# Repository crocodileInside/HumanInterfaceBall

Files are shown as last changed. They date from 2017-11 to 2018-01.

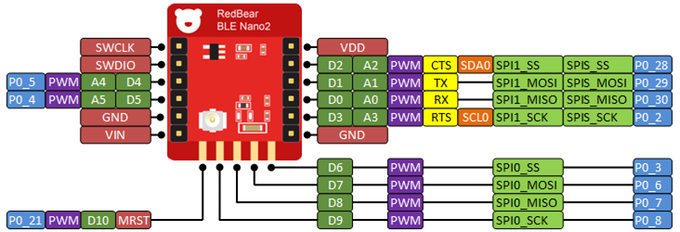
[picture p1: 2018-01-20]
Datasheets/BLE_Nano_v2_Pinout.png

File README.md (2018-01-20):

# HumanInterfaceBall
A ball-shaped, BLE enabled human interface device using a **Bosch BNO055** IMU and a **Bosch BME280** environment sensor for mouse input control.  

## Hardware  
Using a RedBearLabs BLE Nano v2 (**nRF52832**) as MCU and for BLE communication.

## Software  
Written in Arduino, see Arduino folder

### Installation instructions  
In order to setup the required toolchain, follow these instructions:

1. Download and install [Arduino IDE](https://www.arduino.cc/en/Main/Software) >=1.6.12 (tested with 1.6.12)  
2. Install `arduino-nRF5` as described here: https://github.com/sandeepmistry/arduino-nRF5
3. Copy the contents of the `Arduino/libraries/` folder to your Arduino library folder (most likely at `Documents/Arduino/libraries`)
4. The default pin function mapping of our board in Arduino doesn't work with our PCB, so you need to replace your `variant.h` with the one provided in `Arduino/variant.h`  
The original variant.h is found at `C:\Users\<Username>\AppData\Local\Arduino15\packages\sandeepmistry\hardware\nRF5\0.4.0\variants\RedBear_BLENano2`
5. Plug in the DAPLink
6. Install the [mbed Serial Driver](https://os.mbed.com/handbook/Windows-serial-configuration)
7. Open the Arduino IDE (or restart, if it was open)
8. Choose *Tools -> Board -> RedBear BLE Nano 2*
9. Choose *Tools -> Softdevice -> S132*
10. Select the correct serial port for the DAPLink at *Tools -> Port* (sometimes displayed as *BBC:microBit*)
11. Choose *Tools -> Programmer -> CMSIS-DAP*
12. **factory new boards only**: Select *Tools -> nRF5 Flash SoftDevice* and wait for completion
13. Compile and flash the software using Arduino (or hit CTRL+U)
14. Finished!

*Created 01/2018 by C. Locher, M. Schuster, S. Oechslein, N. Rieth, T. Windberg*

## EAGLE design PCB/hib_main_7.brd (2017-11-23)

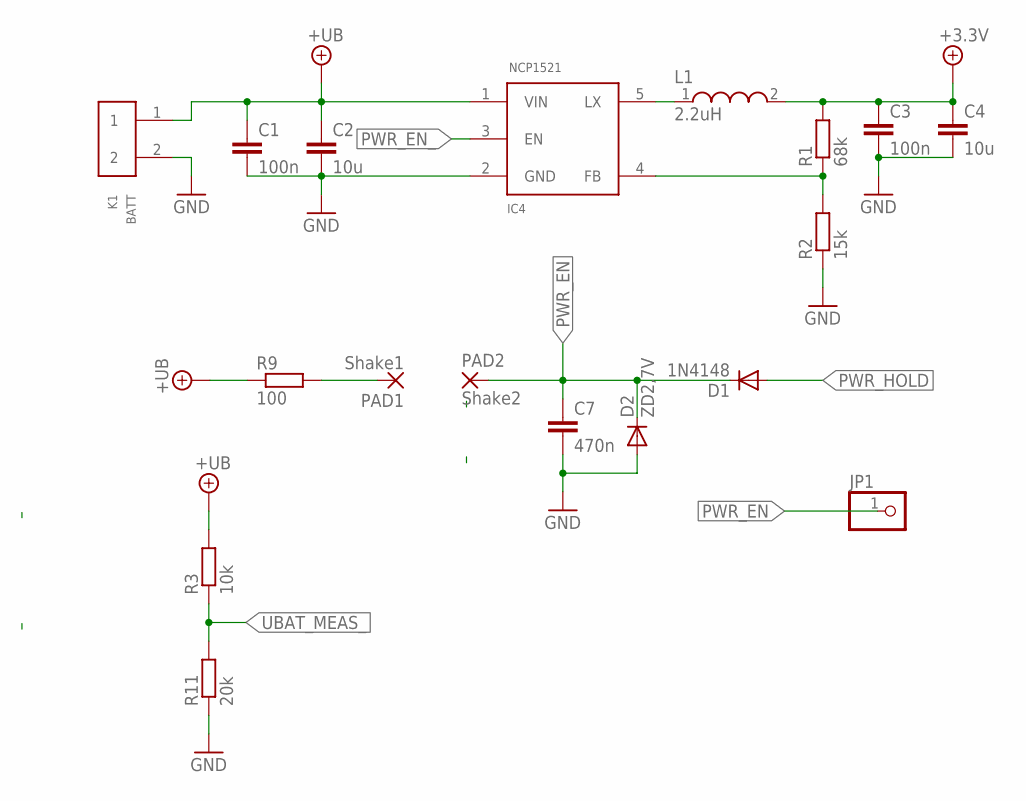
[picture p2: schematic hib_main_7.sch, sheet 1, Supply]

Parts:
C1: 100n; C0805K
C2: 10u; C0805K
C3: 100n; C0805M
C4: 10u; C0805M
C7: 470n; C0805M
D1: 1N4148; MINIMELF
D2: ZD2,7V; MINIMELF
IC4: NCP1521; SOT23-5L
JP1: PINHD-1X1; 1X01
K1: BATT; 620102131822
L1: 2.2uH; WE-MPSB_0805(W=4.0)
PAD1: Shake1; SMD1,27-2,54
PAD2: Shake2; SMD1,27-2,54
R1: 68k; R0603
R2: 15k; R0603
R3: 10k; R0603
R9: 100; R0603
R11: 20k; R0603

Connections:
+3,3V: C3.1, C4.1, L1.2, R1.2; also elsewhere on the board
+UB: C1.1, C2.1, IC4.1 (VIN), K1.1, R3.2, R9.1; also elsewhere on the board
GND: C1.2, C2.2, C3.2, C4.2, C7.2, D2.A, IC4.2 (GND), K1.2, R2.1, R11.1; also elsewhere on the board
unnamed: IC4.5 (LX), L1.1
unnamed: IC4.4 (FB), R1.1, R2.2
unnamed: PAD1.1, R9.2
PWR_EN: C7.1, D1.C, D2.C, JP1.1, PAD2.1
PWR_EN_: IC4.3 (EN); also elsewhere on the board
PWR_HOLD: D1.A; also elsewhere on the board
UBAT_MEAS_: R3.1, R11.2; also elsewhere on the board

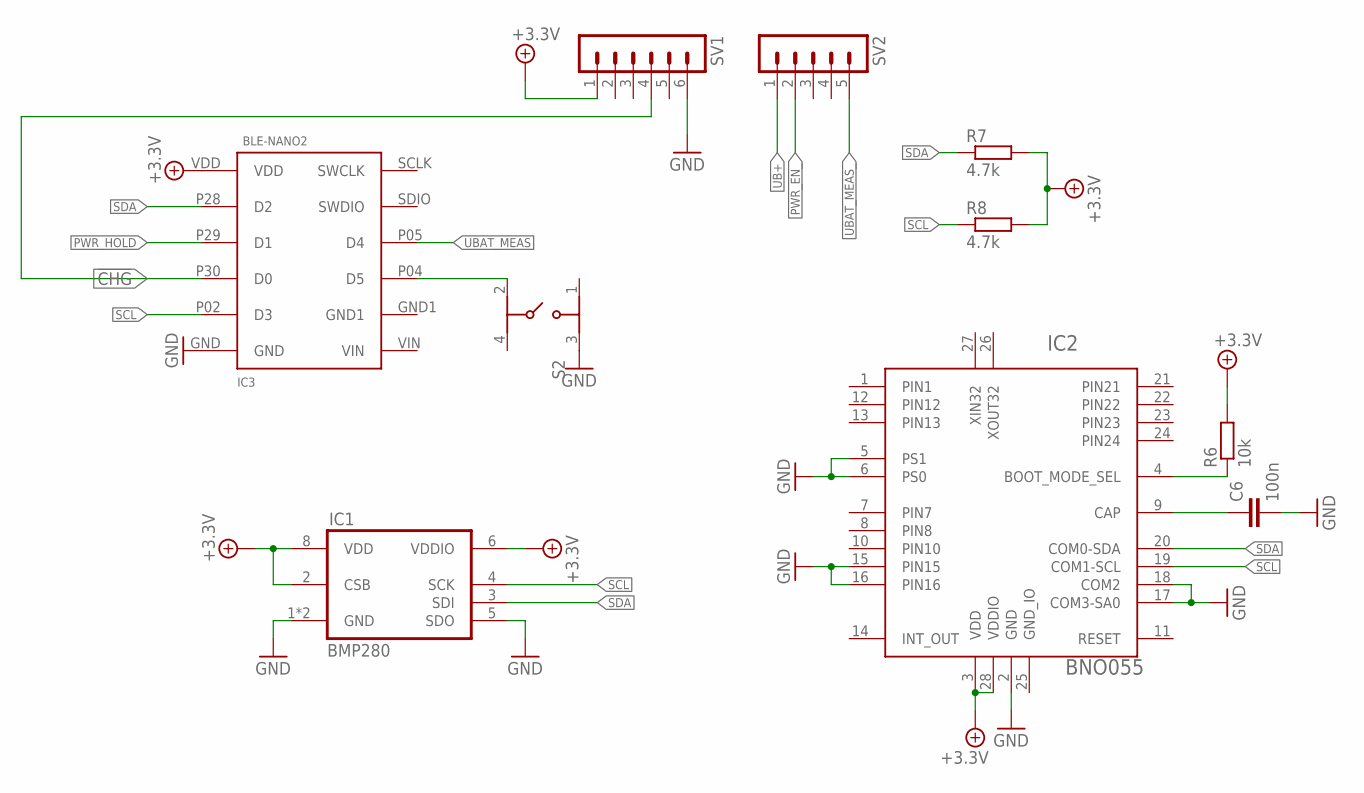
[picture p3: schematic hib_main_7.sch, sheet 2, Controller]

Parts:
C6: 100n; C0805M
IC1: BMP280
IC2: BNO055; LGA-28_3.80X5.20/0.5
IC3: BLE-NANO2
R6: 10k; R0805M
R7, R8: 4.7k; R0805M
S2: 434153017835
SV1: MA06-1
SV2: MA05-1

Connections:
!CHG!: IC3.P30 (D0), SV1.4; also elsewhere on the board
+3,3V: IC1.2 (CSB), IC1.6 (VDDIO), IC1.8 (VDD), IC2.3 (VDD), IC2.28 (VDDIO), IC3.VDD, R6.2, R7.2, R8.2, SV1.1; also elsewhere on the board
GND: C6.2, IC1.1 (GND), IC1.5 (SDO), IC1.7 (GND), IC2.2 (GND), IC2.5 (PS1), IC2.6 (PS0), IC2.15 (PIN15), IC2.16 (PIN16), IC2.17 (COM3-SA0), IC2.18 (COM2), IC3.GND, S2.3 (2), SV1.6; also elsewhere on the board
GND_IO: IC2.25 (GND_IO)
unnamed: C6.1, IC2.9 (CAP)
unnamed: IC2.4 (BOOT_MODE_SEL), R6.1
PWR_EN_: SV2.2; also elsewhere on the board
PWR_HOLD: IC3.P29 (D1); also elsewhere on the board
RESET: IC3.P04 (D5), S2.2 (3)
SCL: IC1.4 (SCK), IC2.19 (COM1-SCL), IC3.P02 (D3), R8.1
SDA: IC1.3 (SDI), IC2.20 (COM0-SDA), IC3.P28 (D2), R7.1
UB+: SV2.1
UBAT_MEAS: IC3.P05 (D4)
UBAT_MEAS_: SV2.5; also elsewhere on the board

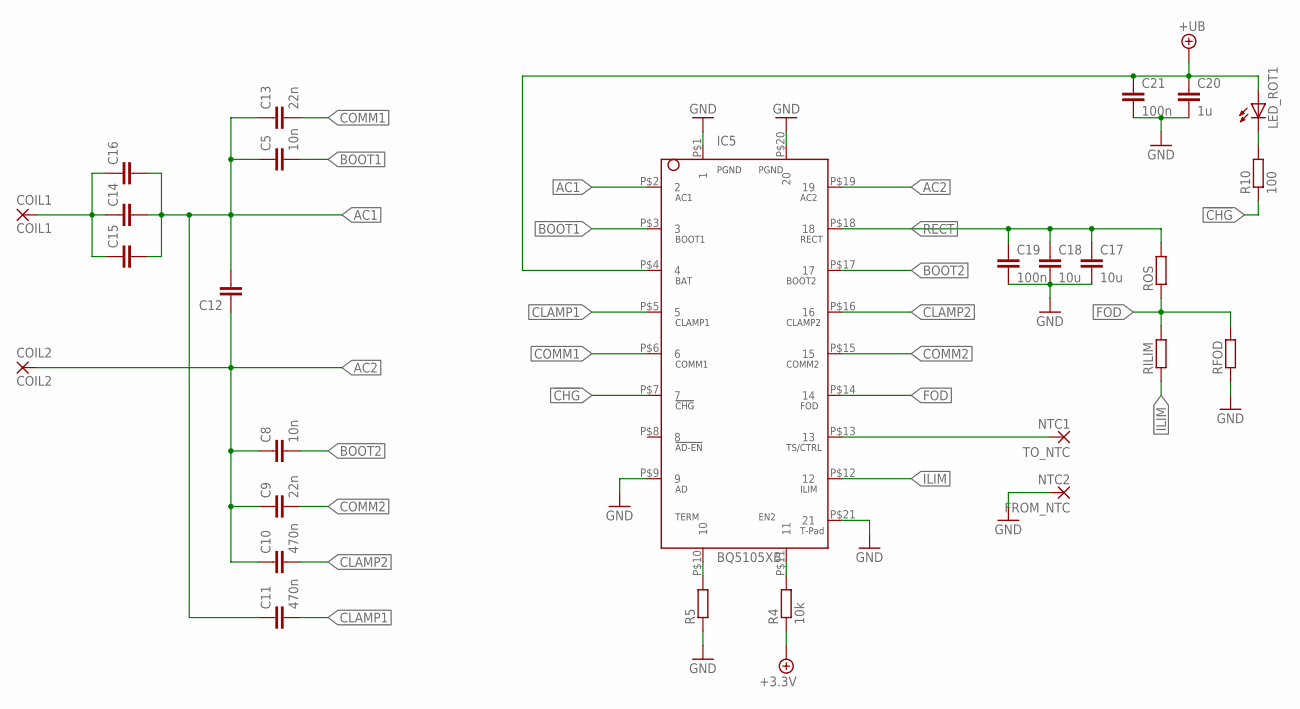
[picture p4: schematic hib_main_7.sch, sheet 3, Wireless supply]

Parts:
C5, C8: 10n; C0603K
C9, C13: 22n; C0603K
C10, C11: 470n; C0603K
C12, C14, C15, C16: C-EUC0603K; C0603K
C17, C18: 10u; C0603K
C19, C21: 100n; C0603K
C20: 1u; C0603K
COIL1: COIL1; SMD1,27-2,54
COIL2: COIL2; SMD1,27-2,54
FROM_NTC: NTC2; SMD1,27-2,54
IC5: BQ5105XB; VQFN_BQ5105B
LED_ROT1: LEDCHIP-LED0603; CHIP-LED0603
R4: 10k; R0805
R5: R-EU_R0603; R0603
R10: 100; R0603
RFOD: R-EU_R0805; R0805
RILIM: R-EU_R0805; R0805
ROS: R-EU_R0805; R0805
TO_NTC: NTC1; SMD1,27-2,54

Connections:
!CHG!: IC5.P$7 (7), R10.1; also elsewhere on the board
+3,3V: R4.1; also elsewhere on the board
+UB: C20.1, C21.1, IC5.P$4 (4), LED_ROT1.A; also elsewhere on the board
AC1: C5.1, C11.1, C12.2, C13.1, C14.2, C15.2, C16.2, IC5.P$2 (2)
AC2: C8.1, C9.1, C10.1, C12.1, COIL2.1, IC5.P$19 (19)
BOOT1: C5.2, IC5.P$3 (3)
BOOT2: C8.2, IC5.P$17 (17)
CLAMP1: C11.2, IC5.P$5 (5)
CLAMP2: C10.2, IC5.P$16 (16)
COMM1: C13.2, IC5.P$6 (6)
COMM2: C9.2, IC5.P$15 (15)
FOD: IC5.P$14 (14), RFOD.2, RILIM.2, ROS.1
GND: C17.2, C18.2, C19.2, C20.2, C21.2, FROM_NTC.1, IC5.P$1 (1), IC5.P$9 (9), IC5.P$20 (20), IC5.P$21 (21), R5.1, RFOD.1; also elsewhere on the board
ILIM: IC5.P$12 (12), RILIM.1
unnamed: C14.1, C15.1, C16.1, COIL1.1
unnamed: IC5.P$10 (10), R5.2
unnamed: IC5.P$11 (11), R4.2
unnamed: LED_ROT1.C, R10.2
RECT: C17.1, C18.1, C19.1, IC5.P$18 (18), ROS.2
TS/CTRL: IC5.P$13 (13), TO_NTC.1

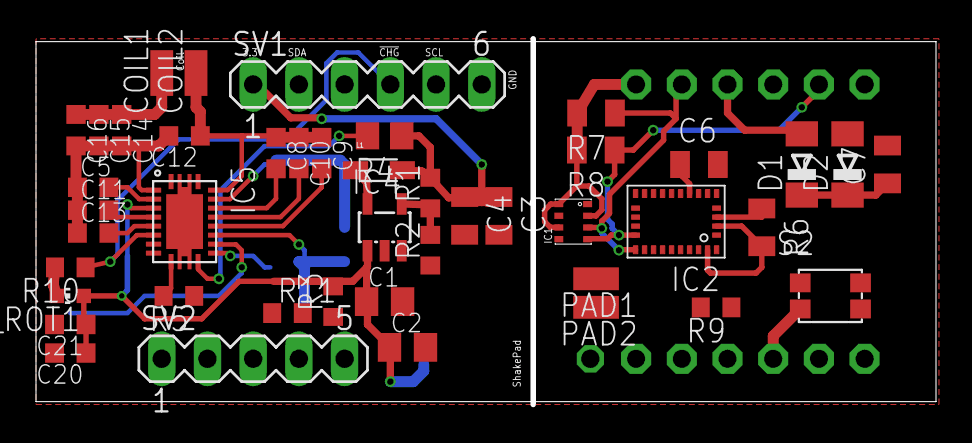
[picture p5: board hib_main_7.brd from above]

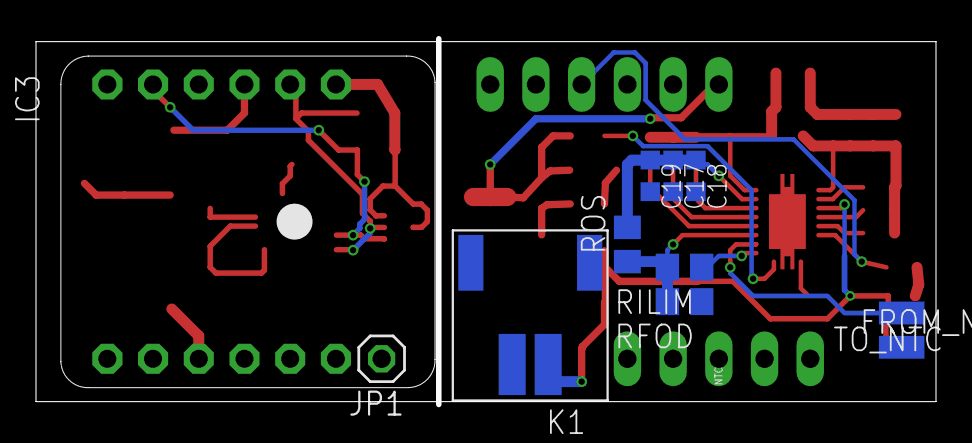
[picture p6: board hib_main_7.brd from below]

Board: 2 copper layers, 50.0 x 20.0 mm, 55 parts (11 on the bottom side), 32 nets.

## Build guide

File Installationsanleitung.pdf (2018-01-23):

# HumanInterfaceBall

Ein Soft-Ball mit einer Bosch BNO055 IMU und einem Bosch BME280 Umweltsensor zur Maussteuerung via Bluetooth 4.0LE.

# Hardware

Basiert auf dem RedBearLabs BLE Nano v2 (nRF52832) als Microcontroller und Bluetooth-Modul.

# Software

Entwickelt in Arduino. Anleitung zur Einrichtung der Entwicklungsumgebung, siehe unten.

## Installationsanleitung

Um mit Arduino den Controller programmieren zu können, muss mit folenden Schritten die Entwicklungsumgebung eingerichtet werden:

1. Herunterladen und installieren der Arduino IDE (https://www.arduino.cc/en/Main/Software) >=1.6.12 (getestet mit 1.6.12)
2. Die Erweiterung arduino-nRF5 nach Anleitung installieren: https://github.com/sandeepmistry/arduino-nRF5
3. Den Inhalt des Ordners Arduino/libraries/ in den eigenen Arduino-Library Ordner kopieren (normalerweise unter Dokumente/Arduino/libraries )

4. Die originale Pinbelegung der arduino-nRF5 Erweiterung passt nicht mit unseren Platinen zusammen, also muss die originale variant.h mit der aus Arduino/variant.h ersetzt werden. Die originale variant.h befindet sich normalerweise unter
C:\Users\
<Benutzername>\AppData\Local\Arduino15\packages\sandeepmistry\hardware\nRF5\0.4.0\variants\RedBear_BLENano2
5. Den Programmieradapter (DAPLink) mit dem Computer verbinden
6. Den mbed Serial Driver (https://os.mbed.com/handbook/Windows-serial-configuration) installieren
7. Die Arduino IDE öffnen (oder neu starten, wenn bereits geöffnet)
8. Werkzeuge -> Board -> RedBear BLE Nano 2 auswählen
9. Werkzeuge -> Softdevice -> S132 auswählen
10. Den korrekten Anschluss des Programmieradapters auswählen unter Werzeuge -> Port (wird manchmal als BBC:microBit angezeigt)
11. Werkzeuge -> Programmer -> CMSIS-DAP auswählen
12. wenn Fabrikneues Board: Werkzeuge -> nRF5 Flash SoftDevice auswählen, und auf Abschluss warten.
13. Software compilieren und hochladen (grüner Haken links oben, oder STRG-U)
14. Fertig!

Erstellt 01/2018 von C. Locher, M. Schuster, S. Oechslein, N. Rieth, T. Windberg

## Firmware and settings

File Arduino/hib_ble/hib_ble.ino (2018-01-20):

#include <SPI.h>
#include <BLEHIDPeripheral.h>
#include <BLEMouse.h>
#include <BLEKeyboard.h>
#include <BLEMultimedia.h>
#include <Wire.h>
#include <Adafruit_Sensor.h>
#include <Adafruit_BNO055.h>
#include <Adafruit_BME280.h>
#include <utility/imumaths.h>

#define MouseBtnLeft   0x01
#define MouseBtnRight  0x02
#define MouseBtnMiddle 0x04

//custom boards may override default pin definitions with BLEHIDPeripheral(PIN_REQ, PIN_RDY, PIN_RST)
BLEHIDPeripheral bleHIDPeripheral = BLEHIDPeripheral();
BLEMouse bleMouse;
BLEKeyboard bleKeyboard;



int buttonState;
int joystickXCenter;
int joystickYCenter;
int Hold_Var=0;
float basePressure = 954.0f;
float accX=0, accY=0,accZ=0;
int pos_acc=0;



Adafruit_BNO055 bno = Adafruit_BNO055();
Adafruit_BME280 bme;



void displaySensorStatus(void)
{
  /* Get the system status values (mostly for debugging purposes) */
  uint8_t system_status, self_test_results, system_error;
  system_status = self_test_results = system_error = 0;
  bno.getSystemStatus(&system_status, &self_test_results, &system_error);

  /* Display the results in the Serial Monitor */
  Serial.println("");
  Serial.print("System Status: 0x");
  Serial.println(system_status, HEX);
  Serial.print("Self Test:     0x");
  Serial.println(self_test_results, HEX);
  Serial.print("System Error:  0x");
  Serial.println(system_error, HEX);
  Serial.println("");
  delay(500);
}

#define LED 0



void doCalibration(){

  int numSamples = 50;
  float pAvg = 0.0f;

  for(int i=0; i<numSamples; i++){
    pAvg += bme.readPressure() / 100.0f;
    
    delay(10);
  }

  pAvg = pAvg / (float)numSamples;
  basePressure = pAvg;
}

void setup() {
  Serial.begin(115200);

  pinMode(LED, OUTPUT);
  digitalWrite(LED, 1);
  /*if (buttonState == LOW) {
    Serial.println(F("BLE HID Peripheral - clearing bond data"));

    // clear bond store 
    bleHIDPeripheral.clearBondStoreData();

  //}*/

  bleHIDPeripheral.clearBondStoreData();
  bleHIDPeripheral.setReportIdOffset(1);

  bleHIDPeripheral.setLocalName("HIB1");
  bleHIDPeripheral.addHID(bleMouse);
  bleHIDPeripheral.addHID(bleKeyboard);

  bleHIDPeripheral.begin();

  Serial.println(F("BLE Human Interface Ball"));

  joystickXCenter = 0;
  joystickYCenter = 0;

  Serial.println("starting BNO");
  if(!bno.begin()){
    Serial.println("no BNO055 detected!");
  }
  Serial.println("BNO setCrystal");
  bno.setExtCrystalUse(false);

  if(!bme.begin()){
    Serial.println("no BME280 detected!");
  }

  doCalibration();
  
  Serial.println("Setup complete");
  
}

int i = 0;
int ledstate = 0;


#define ROLL_AVG_SIZE   32
float gyroAvgArrX[ROLL_AVG_SIZE];
float gyroAvgArrY[ROLL_AVG_SIZE];
float gyroAvgArrZ[ROLL_AVG_SIZE];

float rollAvg(float arr[], float newValue){
  memmove(&(arr[1]), arr, (ROLL_AVG_SIZE-1)*sizeof(float));
  arr[0] = newValue;

  float avg = 0.0f;
  for(int i=0; i<ROLL_AVG_SIZE; i++){
    avg += arr[i];
  }

  return (avg / (float)ROLL_AVG_SIZE);
}


float oriX, oriY, oriZ;
float dOriX, dOriY, dOriZ;
float oriXold = 0.0f, oriYold = 0.0f, oriZold = 0.0f;

float gyroX = 0.0f, gyroY = 0.0f, gyroZ = 0.0f;
float gyroXold = 0.0f, gyroYold = 0.0f, gyroZold = 0.0f;
float dX = 0.0f, dY = 0.0f, dZ = 0.0f;

float sx = 0.0f, sy=0.0f, sz=0.0f;
float avgXold = 0.0f, avgYold = 0.0f, avgZold = 0.0f;


int moveLockTimeout = 0;

void loop() {
  Serial.println("BLE getCentral");
  BLECentral central = bleHIDPeripheral.central();

  //displaySensorStatus();

  uint8_t system, gyro, accel, mag = 0;
  bno.getCalibration(&system, &gyro, &accel, &mag);
  Serial.print("CALIBRATION: Sys=");
  Serial.print(system, DEC);
  Serial.print(" Gyro=");
  Serial.print(gyro, DEC);
  Serial.print(" Accel=");
  Serial.print(accel, DEC);
  Serial.print(" Mag=");
  Serial.println(mag, DEC);

  ledstate = !ledstate;
  digitalWrite(LED, ledstate);
  delay(200);
  
  
  if (central) {
    // central connected to peripheral
    Serial.print(F("Connected to central: "));
    Serial.println(central.address());
  










    while (central.connected()) {

      float pressure = bme.readPressure()/100.0f;
      float dP = pressure - basePressure;
      int tempButtonState = 0;



      //Middle Button Click for scroll function
      imu::Vector<3> acc = bno.getVector(Adafruit_BNO055::VECTOR_LINEARACCEL);

      accX= acc.x();
      accY= acc.y();
      accZ= acc.z();

      if((accY >=10.0f)||(accZ >=10.0f)){
        pos_acc=1;
      }
      if(pos_acc == 1 && (accY<=-10.0f||accZ<=-10.0f)){
        tempButtonState=4;
        }     
      
      //Serial.println(dP);
      if(dP>=20){
        tempButtonState=3;        
      }else if(dP > 1.0f && dP < 20.0f){
          tempButtonState = 1;      // Left Button click
          if(dP < 10.0f){
            Hold_Var=0;
            moveLockTimeout = 50;   // mouse freeze
          }else{
            Hold_Var = 1; 
          }
      }else if(dP < 1.0f && pos_acc != 1){
        tempButtonState = 2;
      }
      
      if ((tempButtonState != buttonState)) {
        buttonState = tempButtonState;
        switch(buttonState)
        {
          case 1: { // Press Mouse Btn Left
            //Serial.println(F("Mouse press"));   // Left press Button
            bleMouse.press(MouseBtnLeft);
            bleMouse.release(MouseBtnMiddle);
            pos_acc=0;
            break;
          }                  
          case 2: { // Release Mouse Btn Left
            //Serial.println(F("Mouse release")); // Left release Button
            if(Hold_Var != 1){
            bleMouse.release(MouseBtnLeft);
            }
            break;
          }
          case 3: { // Click Mouse Btn Right    // Right Button click
            moveLockTimeout = 50;
            bleMouse.click(MouseBtnRight);
            moveLockTimeout = 50;
            break;
          }
          case 4: { // Click Mouse Btn Right    // Middle Button press
            moveLockTimeout = 100;
            bleMouse.press(MouseBtnMiddle);
            moveLockTimeout = 100;
            break;
          }
          default: {break;}       
        }
      }

      imu::Vector<3> gyro = bno.getVector(Adafruit_BNO055::VECTOR_GYROSCOPE);
      gyroX = gyro.x();
      gyroY = gyro.y();
      gyroZ = gyro.z();
      sx += gyroX;
      sy += gyroY;
      sz += gyroZ;
      float avgX = rollAvg(gyroAvgArrX, sx);
      float avgY = rollAvg(gyroAvgArrY, sy);
      float avgZ = rollAvg(gyroAvgArrZ, sz);
      dX = avgX - avgXold;
      dY = avgY - avgYold;
      dZ = avgZ - avgZold;
      avgXold = avgX;
      avgYold = avgY;
      avgZold = avgZ;
      
      int x = dY/5.0f;
      int y = dX/5.0f;
      int z = dZ/5.0f;

      if(moveLockTimeout > 0){
        x = 0;
        y = 0;
        moveLockTimeout--;
      }

      if (x || y) {
        bleMouse.move(x, y, z);
        //Serial.print("Z:"); Serial.print(z);
      }

      ledstate = !ledstate;
      digitalWrite(LED, ledstate);
      
    }

    // central disconnected
    Serial.print(F("Disconnected from central: "));
    Serial.println(central.address());
    bleHIDPeripheral.clearBondStoreData();
  }
}

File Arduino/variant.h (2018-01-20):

/*
  Copyright (c) 2014-2015 Arduino LLC.  All right reserved.
  Copyright (c) 2016 Sandeep Mistry All right reserved.
  This library is free software; you can redistribute it and/or
  modify it under the terms of the GNU Lesser General Public
  License as published by the Free Software Foundation; either
  version 2.1 of the License, or (at your option) any later version.
  This library is distributed in the hope that it will be useful,
  but WITHOUT ANY WARRANTY; without even the implied warranty of
  MERCHANTABILITY or FITNESS FOR A PARTICULAR PURPOSE.
  See the GNU Lesser General Public License for more details.
  You should have received a copy of the GNU Lesser General Public
  License along with this library; if not, write to the Free Software
  Foundation, Inc., 51 Franklin St, Fifth Floor, Boston, MA  02110-1301  USA
*/

#ifndef _VARIANT_REDBEAR_BLE_NANO2_
#define _VARIANT_REDBEAR_BLE_NANO2_

/** Master clock frequency */
#define VARIANT_MCK       (64000000ul)

/*----------------------------------------------------------------------------
 *        Headers
 *----------------------------------------------------------------------------*/

#include "WVariant.h"

#ifdef __cplusplus
extern "C"
{
#endif // __cplusplus

// Number of pins defined in PinDescription array
#define PINS_COUNT           (14u)
#define NUM_DIGITAL_PINS     (14u)
#define NUM_ANALOG_INPUTS    (6u)
#define NUM_ANALOG_OUTPUTS   (0u)

// LEDs
#define LED_BUILTIN           13

/*
 * Analog pins
 */
#define PIN_A0               (0)
#define PIN_A1               (1)
#define PIN_A2               (2)
#define PIN_A3               (3)
#define PIN_A4               (4)
#define PIN_A5               (5)

static const uint8_t A0  = PIN_A0 ;
static const uint8_t A1  = PIN_A1 ;
static const uint8_t A2  = PIN_A2 ;
static const uint8_t A3  = PIN_A3 ;
static const uint8_t A4  = PIN_A4 ;
static const uint8_t A5  = PIN_A5 ;
#define ADC_RESOLUTION    14

/*
 * Serial interfaces
 */
// Serial
#define PIN_SERIAL_RX       (4)
#define PIN_SERIAL_TX       (1)

/*
 * SPI Interfaces
 */
#define SPI_INTERFACES_COUNT 1

#define PIN_SPI_MISO         (8)
#define PIN_SPI_MOSI         (7)
#define PIN_SPI_SCK          (9)

static const uint8_t SS   = 6 ;
static const uint8_t MOSI = PIN_SPI_MOSI ;
static const uint8_t MISO = PIN_SPI_MISO ;
static const uint8_t SCK  = PIN_SPI_SCK ;

/*
 * Wire Interfaces
 */
#define WIRE_INTERFACES_COUNT 1

#define PIN_WIRE_SDA         (2u)
#define PIN_WIRE_SCL         (3u)

static const uint8_t SDA = PIN_WIRE_SDA;
static const uint8_t SCL = PIN_WIRE_SCL;

#ifdef __cplusplus
}
#endif

/*----------------------------------------------------------------------------
 *        Arduino objects - C++ only
 *----------------------------------------------------------------------------*/

#endif

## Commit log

2017-11-23 added ble_app_uart
    [hib_main.brd, hib_main.sch, hib_main_7.brd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]
2017-11-23 added i2c example
2018-01-17 added arduino version

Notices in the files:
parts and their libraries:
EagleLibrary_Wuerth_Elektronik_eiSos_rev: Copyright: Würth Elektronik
